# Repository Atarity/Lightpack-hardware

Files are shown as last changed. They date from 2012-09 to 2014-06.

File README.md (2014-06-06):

Lightpack-hardware
==================

Lightpack hardware schematics and layouts in CAD Eagle 6+ . This repo was started privately by reason of R&amp;D.

-------------------------
All updates stores in [CHANGELOG] (/Atarity/Lightpack-hardware/blob/master/CHANGELOG) file
* L &mdash; DIY versions
* T &mdash; mass-production preview versions

No GERBERs, no extension-hashed backups. All research and derivatives in branches.

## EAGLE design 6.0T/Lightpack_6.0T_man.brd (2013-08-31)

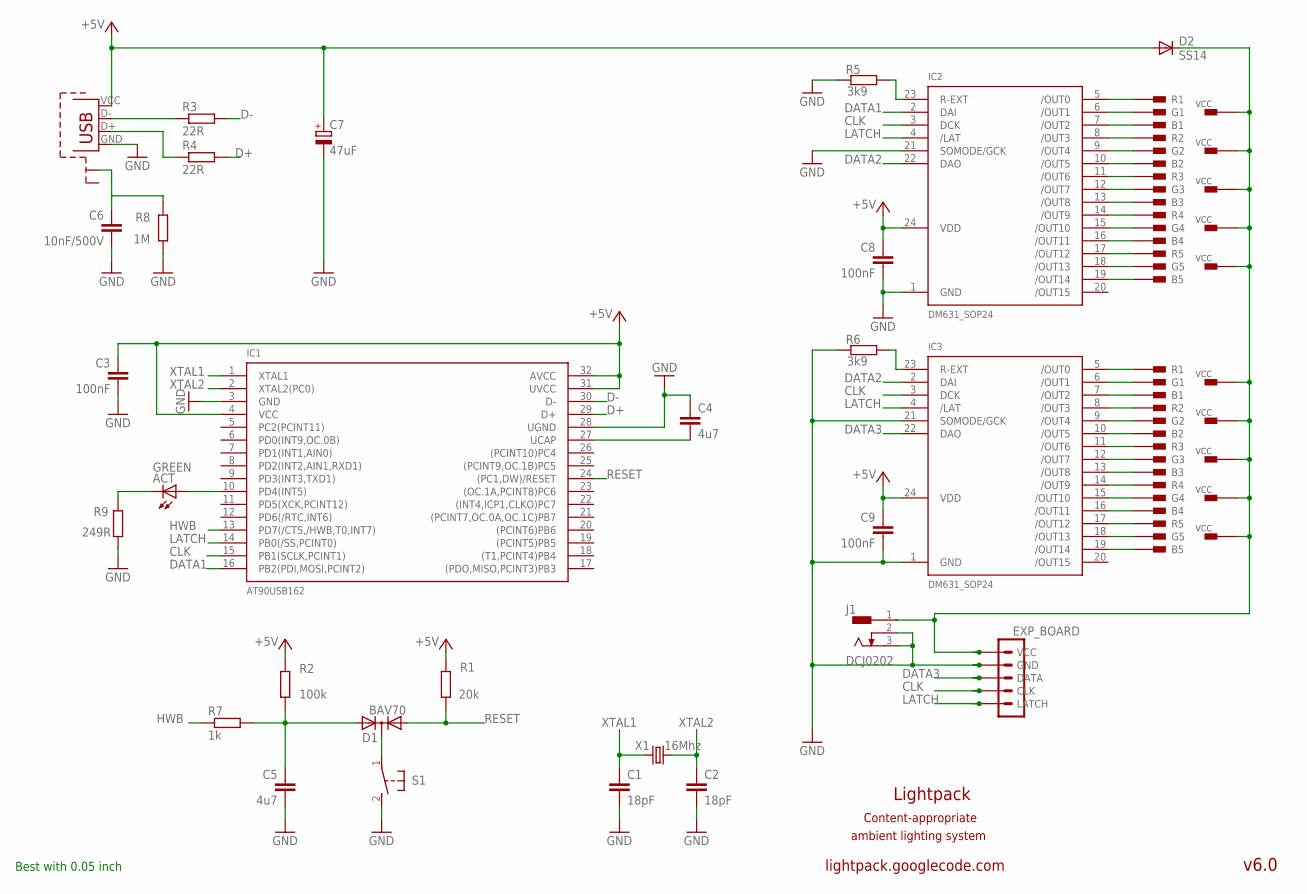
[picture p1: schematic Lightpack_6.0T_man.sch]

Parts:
ACT: GREEN; LED3MM
C1, C2: 18pF; C0805
C3, C8, C9: 100nF; C0805
C4, C5: 4u7; C0805
C6: 10nF/500V; C0805
C7: 47uF; SMC_D
CN1: USB-MICRO-B-EVT; USB-MICRO-B-UNIVERSAL-SOLID-FOOTS
CN2: RJ11-5P-REEL-LIGHTPACK6T2; RJ11-1XN-5P
CN3: RJ11-5P-REEL-MAIN; RJ11-1XN-5P
D1: BAV70; SOT23
D2: SS14; SMB
EXP_BOARD: MA05-1
IC1: AT90USB162; TQFP32
IC2, IC3: DM631_SOP24; SOP24-300-1.27
J1: DCJ0202
R1: 20k; R0805
R2: 100k; R0805
R3, R4: 22R; R0805
R5, R6: 3k9; R0805
R7: 1k; R0805
R8: 1M; R0805
R9: 249R; R0805
S1: 31-XX; B3F-31XX
X1: 16Mhz; HC49UP

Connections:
+5V: C3.1, C7.+, C8.1, C9.1, CN1.VCC (VBUS), D2.A, IC1.4 (VCC), IC1.31 (UVCC), IC1.32 (AVCC), IC2.24 (VDD), IC3.24 (VDD), R1.2, R2.2
CLK: EXP_BOARD.2 (CLK), IC1.15 (PB1(SCLK,PCINT1)), IC2.3 (DCK), IC3.3 (DCK)
D+: IC1.29 (D+), R4.2
D-: IC1.30 (D-), R3.2
DATA1: IC1.16 (PB2(PDI,MOSI,PCINT2)), IC2.2 (DAI)
DATA2: IC2.22 (DAO), IC3.2 (DAI)
DATA3: EXP_BOARD.3 (DATA), IC3.22 (DAO)
GND: C1.2, C2.2, C3.2, C4.1, C5.2, C6.1, C7.-, C8.2, C9.2, CN1.GND, EXP_BOARD.4 (GND), IC1.3 (GND), IC1.28 (UGND), IC2.1 (GND), IC2.21 (SOMODE/GCK), IC3.1 (GND), IC3.21 (SOMODE/GCK), J1.2, J1.3, R5.1, R6.1, R8.1, R9.1, S1.2 (S)
HWB: IC1.13 (PD7(/CTS,/HWB,T0,INT7)), R7.1
LATCH: EXP_BOARD.1 (LATCH), IC1.14 (PB0(/SS,PCINT0)), IC2.4 (/LAT), IC3.4 (/LAT)
unnamed: IC2.23 (R-EXT), R5.2
unnamed: CN3.R2, IC3.8 (/OUT3)
unnamed: ACT.A, IC1.10 (PD4(INT5))
unnamed: CN2.R5 (R1), IC2.5 (/OUT0)
unnamed: CN2.G5 (G1), IC2.6 (/OUT1)
unnamed: CN2.B5 (B1), IC2.7 (/OUT2)
unnamed: CN2.R4 (R2), IC2.8 (/OUT3)
unnamed: CN2.G4 (G2), IC2.9 (/OUT4)
unnamed: CN2.B4 (B2), IC2.10 (/OUT5)
unnamed: CN2.R1 (R3), IC2.11 (/OUT6)
unnamed: CN2.G1 (G3), IC2.12 (/OUT7)
unnamed: CN2.B1 (B3), IC2.13 (/OUT8)
unnamed: CN2.R2 (R4), IC2.14 (/OUT9)
unnamed: D1.3 (C), S1.1
unnamed: C4.2, IC1.27 (UCAP)
unnamed: CN3.R1, IC3.5 (/OUT0)
unnamed: CN3.G1, IC3.6 (/OUT1)
unnamed: CN3.B1, IC3.7 (/OUT2)
unnamed: CN3.G2, IC3.9 (/OUT4)
unnamed: CN3.B2, IC3.10 (/OUT5)
unnamed: CN3.R3, IC3.11 (/OUT6)
unnamed: CN3.G3, IC3.12 (/OUT7)
unnamed: CN3.R4, IC3.14 (/OUT9)
unnamed: CN3.B3, IC3.13 (/OUT8)
unnamed: CN3.G4, IC3.15 (/OUT10)
unnamed: CN3.B4, IC3.16 (/OUT11)
unnamed: CN2.G2 (G4), IC2.15 (/OUT10)
unnamed: CN2.B2 (B4), IC2.16 (/OUT11)
unnamed: IC3.23 (R-EXT), R6.2
unnamed: CN1.D-, R3.1
unnamed: CN1.D+, R4.1
unnamed: ACT.K (C), R9.2
unnamed: CN2.R3 (R5), IC2.17 (/OUT12)
unnamed: CN2.G3 (G5), IC2.18 (/OUT13)
unnamed: CN2.B3 (B5), IC2.19 (/OUT14)
unnamed: CN3.R5, IC3.17 (/OUT12)
unnamed: CN3.G5, IC3.18 (/OUT13)
unnamed: CN3.B5, IC3.19 (/OUT14)
unnamed: C6.2, CN1.P$4 (SHIELD1), R8.2
unnamed: C5.1, D1.2 (A2), R2.1, R7.2
unnamed: CN2.VCC1 (VCC3), CN2.VCC2 (VCC4), CN2.VCC3 (VCC5), CN2.VCC4 (VCC2), CN2.VCC5 (VCC1), CN3.VCC1, CN3.VCC2, CN3.VCC3, CN3.VCC4, CN3.VCC5, D2.C, EXP_BOARD.5 (VCC), J1.1
RESET: D1.1 (A1), IC1.24 ((PC1,DW)/RESET), R1.1
XTAL1: C1.1, IC1.1 (XTAL1), X1.1
XTAL2: C2.1, IC1.2 (XTAL2(PC0)), X1.2

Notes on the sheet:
lightpack.googlecode.com
Lightpack
ambient lighting system
v6.0
Content-appropriate
Best with 0.05 inch

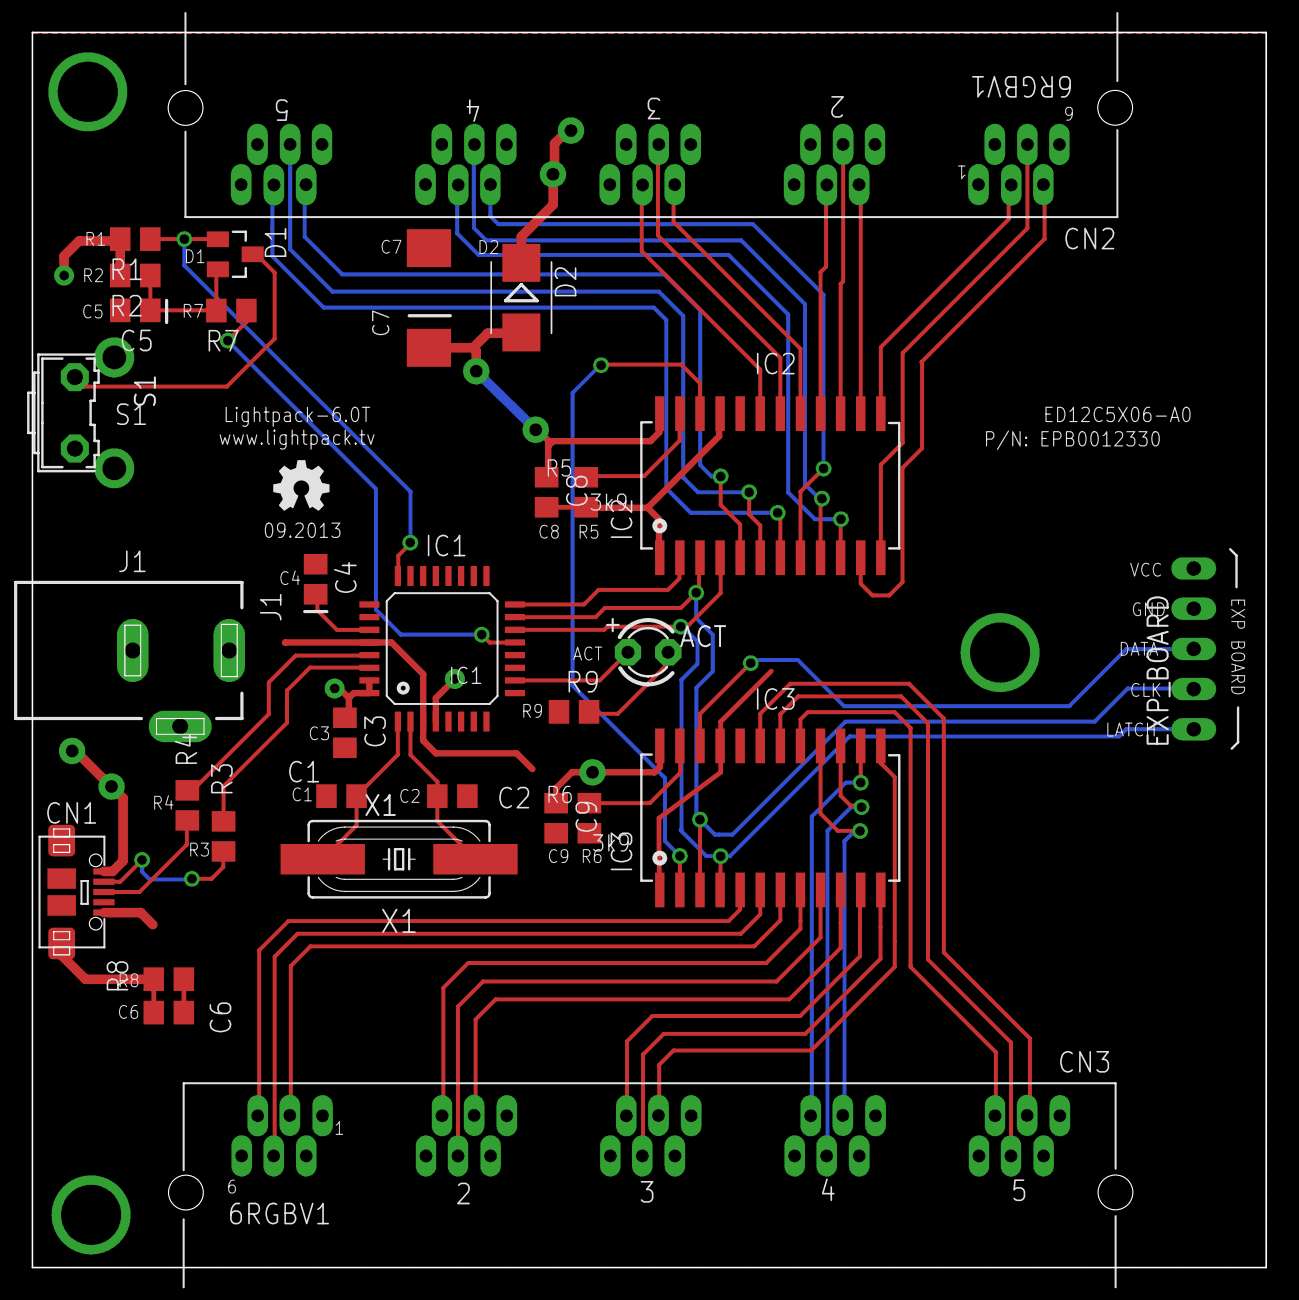
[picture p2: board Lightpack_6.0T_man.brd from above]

Board: 2 copper layers, 78.0 x 78.1 mm, 31 parts (0 on the bottom side), 54 nets.

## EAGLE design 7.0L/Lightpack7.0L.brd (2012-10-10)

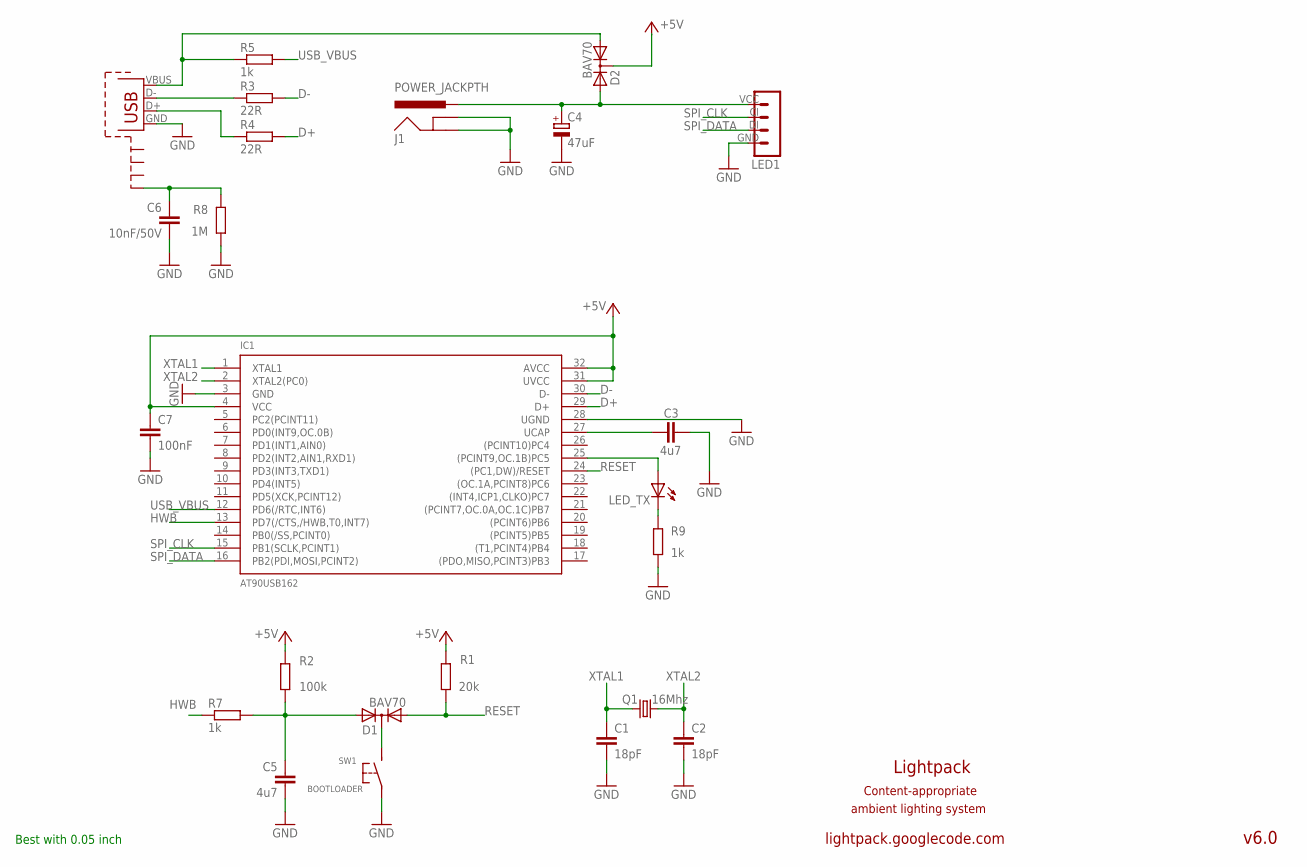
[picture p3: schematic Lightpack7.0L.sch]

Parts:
C1, C2: 18pF; C1206
C3, C5: 4u7; C1206
C4: 47uF; D/7343-31W
C6: 10nF/50V; C1206
C7: 100nF; C1206
D1, D2: BAV70; SOT23
IC1: AT90USB162; TQFP32
J1: POWER_JACKPTH; POWER_JACK_PTH
LED1: RGB_LED_STRIP; MA04-1
LED_TX: GREEN; CHIPLED_0805
Q1: 16Mhz; HC49UP
R1: 20k; R1206
R2: 100k; R1206
R3, R4: 22R; R1206
R5, R7, R9: 1k; R1206
R8: 1M; R1206
SW1: BOOTLOADER; BUTTON-SMD
X1: USB-MB-S

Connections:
+5V: C7.1, IC1.4 (VCC), IC1.31 (UVCC), IC1.32 (AVCC), R1.2, R2.1 (2)
D+: IC1.29 (D+), R4.2
D-: IC1.30 (D-), R3.2
GND: C1.2, C2.2, C3.1, C4.-, C5.2, C6.2, C7.2, IC1.3 (GND), IC1.28 (UGND), J1.GND, J1.GNDBREAK, LED1.GND, R8.1, R9.1, SW1.1, X1.GND
HWB: IC1.13 (PD7(/CTS,/HWB,T0,INT7)), R7.1
unnamed: R4.1, X1.D+
unnamed: D2.1 (A1), R5.1, X1.VBUS
unnamed: R3.1, X1.D-
unnamed: C4.+, D2.2 (A2), J1.PWR, LED1.VCC
unnamed: IC1.25 ((PCINT9,OC.1B)PC5), LED_TX.A
unnamed: C6.1, R8.2, X1.SHIELD4
unnamed: LED_TX.C, R9.2
unnamed: D1.3 (C), SW1.2
unnamed: C5.1, D1.2 (A2), R2.2 (1), R7.2
unnamed: C3.2, IC1.27 (UCAP)
RESET: D1.1 (A1), IC1.24 ((PC1,DW)/RESET), R1.1
SPI_CLK: IC1.15 (PB1(SCLK,PCINT1)), LED1.CI
SPI_DATA: IC1.16 (PB2(PDI,MOSI,PCINT2)), LED1.DI
USB_VBUS: IC1.12 (PD6(/RTC,INT6)), R5.2
XTAL1: C1.1, IC1.1 (XTAL1), Q1.1
XTAL2: C2.1, IC1.2 (XTAL2(PC0)), Q1.2

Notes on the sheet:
lightpack.googlecode.com
Lightpack
ambient lighting system
v6.0
Content-appropriate
Best with 0.05 inch

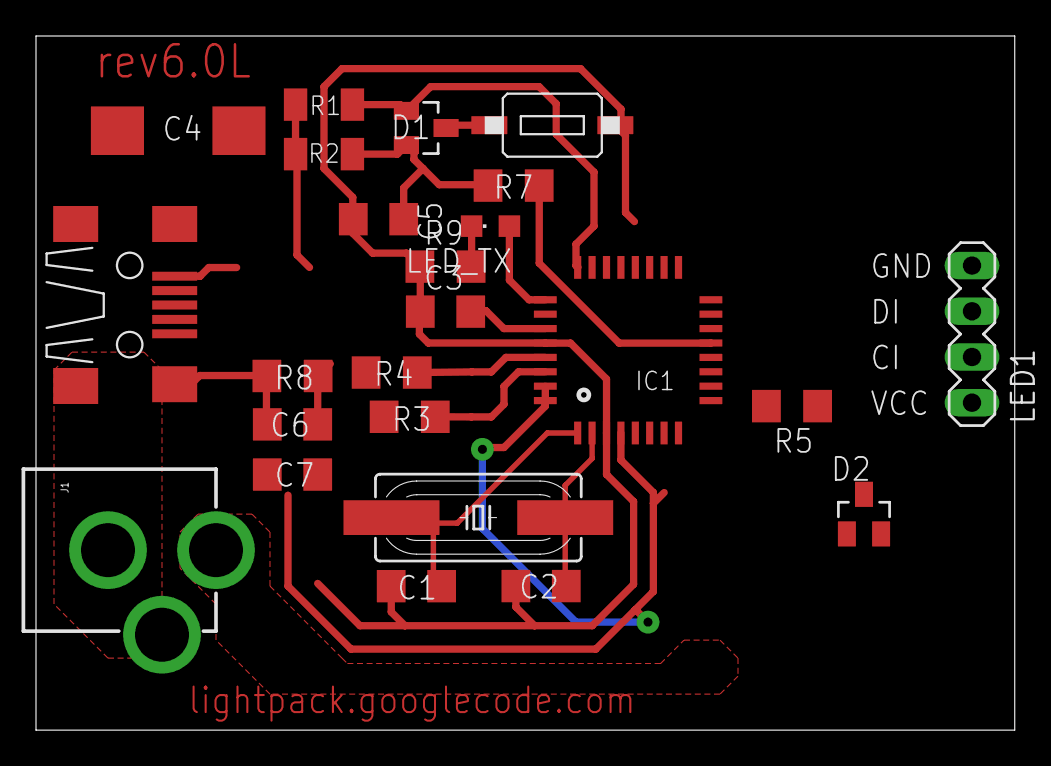
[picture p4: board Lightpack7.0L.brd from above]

Board: 2 copper layers, 54.4 x 38.6 mm, 24 parts (0 on the bottom side), 21 nets.

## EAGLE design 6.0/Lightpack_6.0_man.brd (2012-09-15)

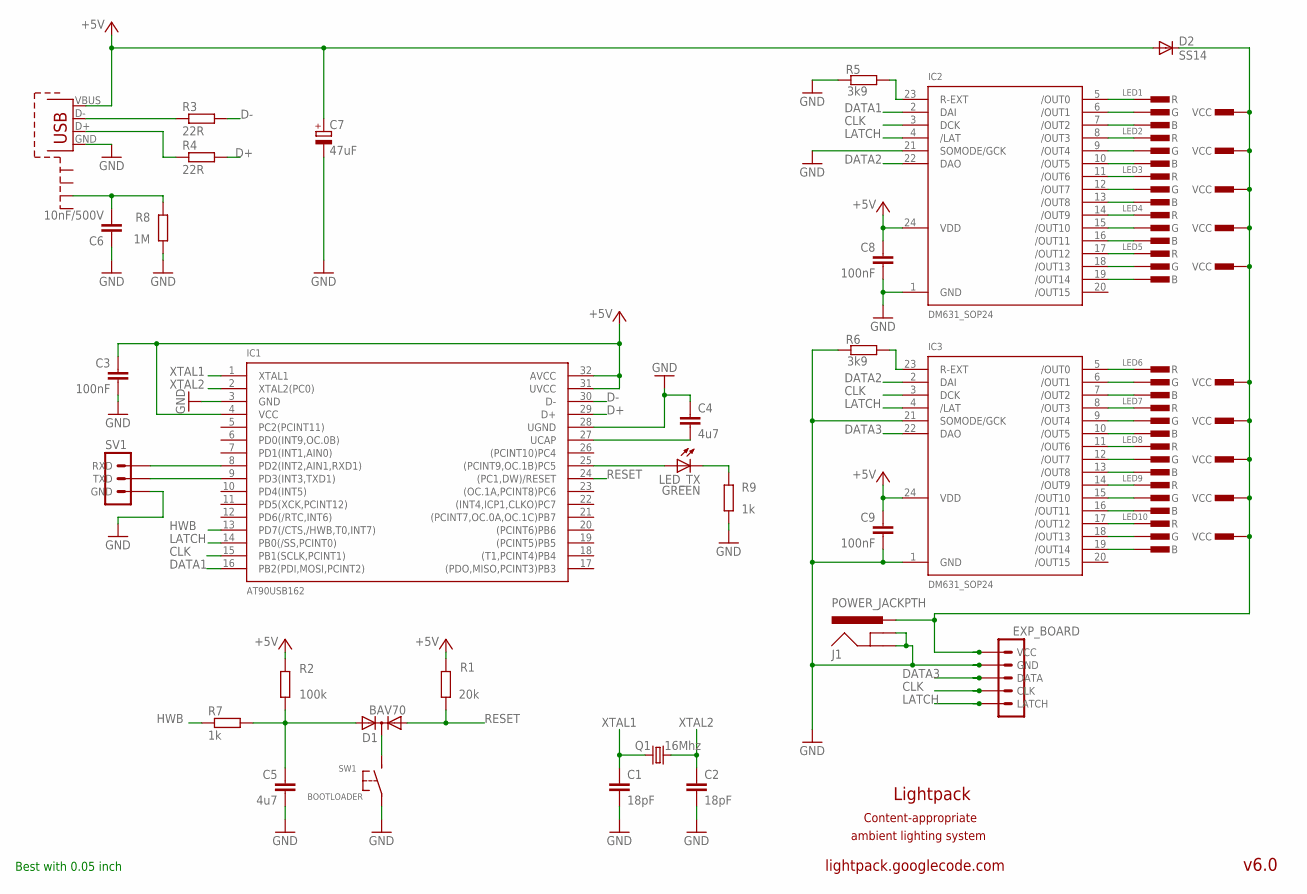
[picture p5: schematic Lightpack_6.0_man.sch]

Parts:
C1, C2: 18pF; C0805
C3, C8, C9: 100nF; C0805
C4, C5: 4u7; C0805
C6: 10nF/500V; C0805
C7: 47uF; SMC_D
D1: BAV70; SOT23
D2: SS14; SMB
EXP_BOARD: MA05-1
IC1: AT90USB162; TQFP32
IC2, IC3: DM631_SOP24; SOP24-300-1.27
J1: POWER_JACKPTH; POWER_JACK_PTH
LED1, LED2, LED3, LED4, LED5, LED6, LED7, LED8, LED9, LED10: CON-RGB-LED; CON-RGB-LED-TH
LED_TX: GREEN; CHIPLED_0805
Q1: 16Mhz; HC49UP
R1: 20k; R0805
R2: 100k; R0805
R3, R4: 22R; R0805
R5, R6: 3k9; R0805
R7, R9: 1k; R0805
R8: 1M; R0805
SV1: UART3
SW1: BOOTLOADER; BUTTON-SMD
X1: USB-MB-S

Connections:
+5V: C3.1, C7.+, C8.1, C9.1, D2.A, IC1.4 (VCC), IC1.31 (UVCC), IC1.32 (AVCC), IC2.24 (VDD), IC3.24 (VDD), R1.2, R2.2, X1.VBUS
CLK: EXP_BOARD.2 (CLK), IC1.15 (PB1(SCLK,PCINT1)), IC2.3 (DCK), IC3.3 (DCK)
D+: IC1.29 (D+), R4.2
D-: IC1.30 (D-), R3.2
DATA1: IC1.16 (PB2(PDI,MOSI,PCINT2)), IC2.2 (DAI)
DATA2: IC2.22 (DAO), IC3.2 (DAI)
DATA3: EXP_BOARD.3 (DATA), IC3.22 (DAO)
GND: C1.2, C2.2, C3.2, C4.1, C5.2, C6.1, C7.-, C8.2, C9.2, EXP_BOARD.4 (GND), IC1.3 (GND), IC1.28 (UGND), IC2.1 (GND), IC2.21 (SOMODE/GCK), IC3.1 (GND), IC3.21 (SOMODE/GCK), J1.GND, J1.GNDBREAK, R5.1, R6.1, R8.1, R9.1, SV1.1-L (GND), SW1.1, X1.GND
HWB: IC1.13 (PD7(/CTS,/HWB,T0,INT7)), R7.1
LATCH: EXP_BOARD.1 (LATCH), IC1.14 (PB0(/SS,PCINT0)), IC2.4 (/LAT), IC3.4 (/LAT)
unnamed: IC2.23 (R-EXT), R5.2
unnamed: IC3.8 (/OUT3), LED7.3.R (R)
unnamed: IC1.8 (PD2(INT2,AIN1,RXD1)), SV1.2 (RXD)
unnamed: IC1.9 (PD3(INT3,TXD1)), SV1.3-R (TXD)
unnamed: IC2.5 (/OUT0), LED1.3.R (R)
unnamed: IC2.6 (/OUT1), LED1.2.G (G)
unnamed: IC2.7 (/OUT2), LED1.1.B (B)
unnamed: IC1.25 ((PCINT9,OC.1B)PC5), LED_TX.A
unnamed: IC2.8 (/OUT3), LED2.3.R (R)
unnamed: IC2.9 (/OUT4), LED2.2.G (G)
unnamed: IC2.10 (/OUT5), LED2.1.B (B)
unnamed: IC2.11 (/OUT6), LED3.3.R (R)
unnamed: IC2.12 (/OUT7), LED3.2.G (G)
unnamed: IC2.13 (/OUT8), LED3.1.B (B)
unnamed: IC2.14 (/OUT9), LED4.3.R (R)
unnamed: C4.2, IC1.27 (UCAP)
unnamed: IC3.5 (/OUT0), LED6.3.R (R)
unnamed: IC3.6 (/OUT1), LED6.2.G (G)
unnamed: IC3.7 (/OUT2), LED6.1.B (B)
unnamed: IC3.9 (/OUT4), LED7.2.G (G)
unnamed: IC3.10 (/OUT5), LED7.1.B (B)
unnamed: IC3.11 (/OUT6), LED8.3.R (R)
unnamed: IC3.12 (/OUT7), LED8.2.G (G)
unnamed: IC3.14 (/OUT9), LED9.3.R (R)
unnamed: IC3.13 (/OUT8), LED8.1.B (B)
unnamed: IC3.15 (/OUT10), LED9.2.G (G)
unnamed: IC3.16 (/OUT11), LED9.1.B (B)
unnamed: IC2.15 (/OUT10), LED4.2.G (G)
unnamed: IC2.16 (/OUT11), LED4.1.B (B)
unnamed: IC3.23 (R-EXT), R6.2
unnamed: R3.1, X1.D-
unnamed: R4.1, X1.D+
unnamed: LED_TX.C, R9.2
unnamed: IC2.17 (/OUT12), LED5.3.R (R)
unnamed: IC2.18 (/OUT13), LED5.2.G (G)
unnamed: IC2.19 (/OUT14), LED5.1.B (B)
unnamed: IC3.17 (/OUT12), LED10.3.R (R)
unnamed: IC3.18 (/OUT13), LED10.2.G (G)
unnamed: IC3.19 (/OUT14), LED10.1.B (B)
unnamed: C6.2, R8.2, X1.SHIELD3
unnamed: D1.3 (C), SW1.2
unnamed: C5.1, D1.2 (A2), R2.1, R7.2
unnamed: D2.C, EXP_BOARD.5 (VCC), J1.PWR, LED1.4.VCC (VCC), LED2.4.VCC (VCC), LED3.4.VCC (VCC), LED4.4.VCC (VCC), LED5.4.VCC (VCC), LED6.4.VCC (VCC), LED7.4.VCC (VCC), LED8.4.VCC (VCC), LED9.4.VCC (VCC), LED10.4.VCC (VCC)
RESET: D1.1 (A1), IC1.24 ((PC1,DW)/RESET), R1.1
XTAL1: C1.1, IC1.1 (XTAL1), Q1.1
XTAL2: C2.1, IC1.2 (XTAL2(PC0)), Q1.2

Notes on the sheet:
lightpack.googlecode.com
Lightpack
ambient lighting system
v6.0
Content-appropriate
Best with 0.05 inch

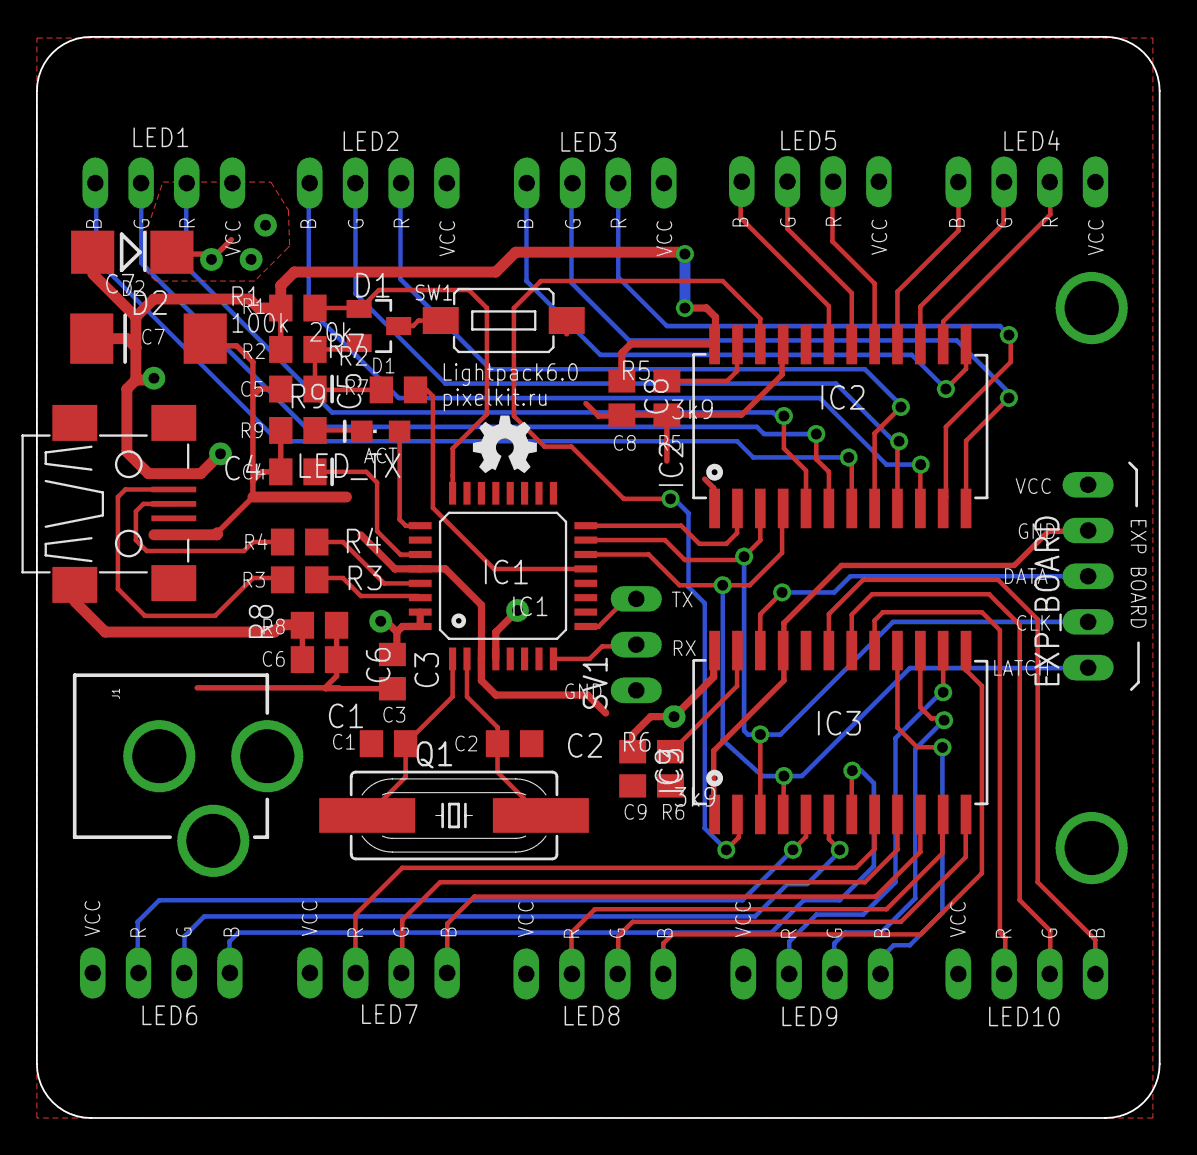
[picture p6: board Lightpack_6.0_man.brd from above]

Board: 2 copper layers, 62.4 x 60.1 mm, 40 parts (0 on the bottom side), 56 nets.

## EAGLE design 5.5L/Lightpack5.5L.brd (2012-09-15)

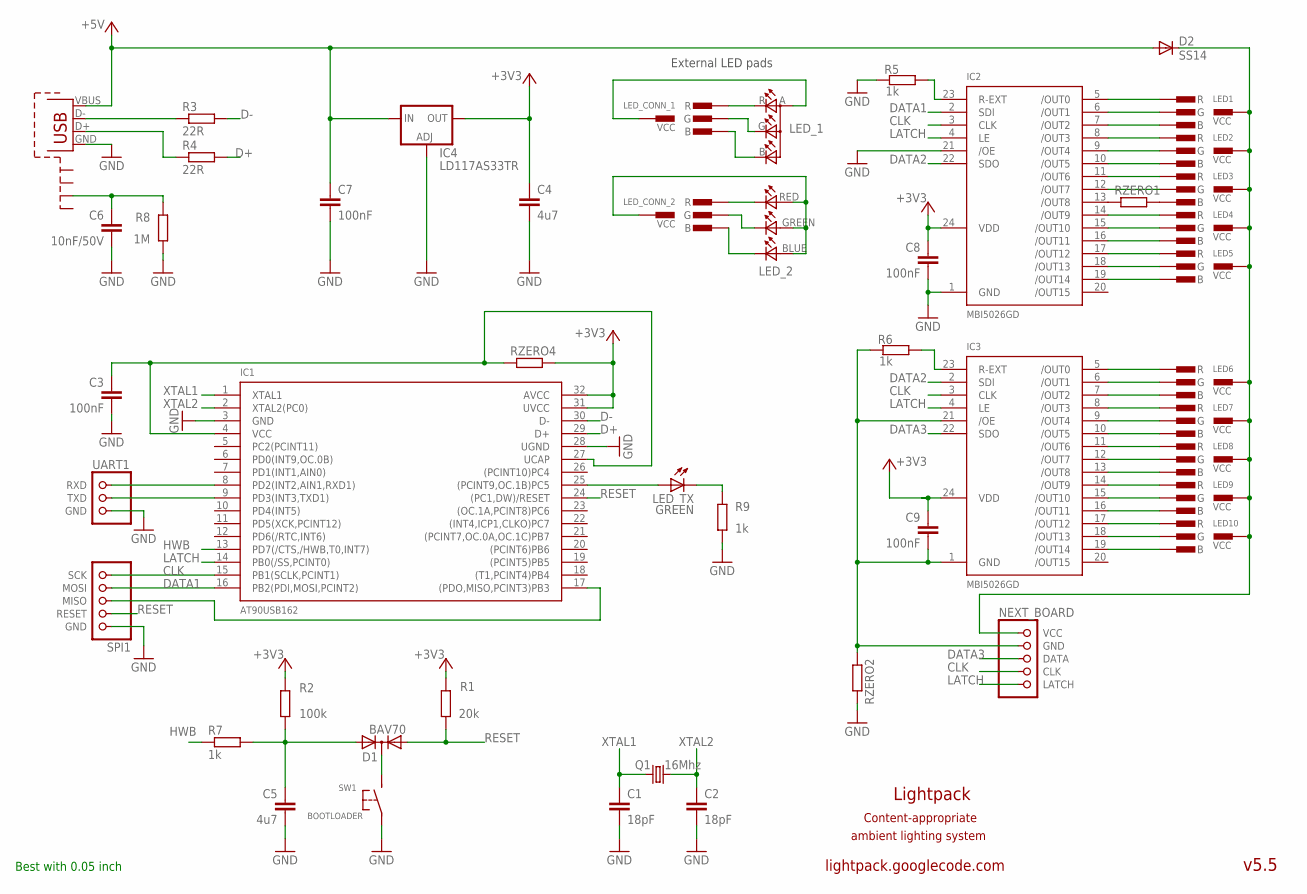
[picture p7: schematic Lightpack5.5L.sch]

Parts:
C1, C2: 18pF; C1206
C3, C7, C8, C9: 100nF; C1206
C4, C5: 4u7; C1206
C6: 10nF/50V; C1206
D1: BAV70; SOT23
D2: SS14; SMB
IC1: AT90USB162; TQFP32
IC2, IC3: MBI5026GD; SOP24-300-1.27
IC4: LD117AS33TR; SOT223
LED1, LED2, LED3, LED6, LED7, LED8, LED9, LED10: CON-RGB-LED
LED4, LED5: CON-RGB-LEDVCC-INDENT; CON-RGB-LED-WITH-VCC-INDENT
LED_1: CLV1A-FKB
LED_2: TOPLED-3SMD5X5; SMD-RGB-5X5
LED_CONN_1, LED_CONN_2: CON-RGB-LED
LED_TX: GREEN; CHIPLED_0805
NEXT_BOARD: LED_DRIVER_BOARD; DATA-CLK-LATCH
Q1: 16Mhz; HC49UP
R1: 20k; R1206
R2: 100k; R1206
R3, R4: 22R; R1206
R5, R6, R7, R9: 1k; R1206
R8: 1M; R1206
RZERO1, RZERO4: R-EU_R1206_2; R1206
RZERO2: 0; R1206
SPI1: SPI_RST_GND_CONN; SPI_5
SW1: BOOTLOADER; BUTTON-SMD
UART1: UART
X1: USB-MB-S

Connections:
+3V3: C4.1, C8.1, C9.1, IC1.31 (UVCC), IC1.32 (AVCC), IC2.24 (VDD), IC3.24 (VDD), IC4.4 (OUT), R1.2, R2.1 (2), RZERO4.1 (2)
+5V: C7.1, D2.A, IC4.3 (IN), X1.VBUS
CLK: IC1.15 (PB1(SCLK,PCINT1)), IC2.3 (CLK), IC3.3 (CLK), NEXT_BOARD.CLK, SPI1.SCK
D+: IC1.29 (D+), R4.2
D-: IC1.30 (D-), R3.2
DATA1: IC1.16 (PB2(PDI,MOSI,PCINT2)), IC2.2 (SDI), SPI1.MOSI
DATA2: IC2.22 (SDO), IC3.2 (SDI)
DATA3: IC3.22 (SDO), NEXT_BOARD.DATA
GND: C1.2, C2.2, C3.2, C4.2, C5.2, C6.2, C7.2, C8.2, IC1.3 (GND), IC1.28 (UGND), IC2.1 (GND), IC2.21 (/OE), IC4.1 (ADJ), R5.1, R8.1, R9.1, RZERO2.1 (2), SPI1.GND, SW1.1, UART1.GND, X1.GND
HWB: IC1.13 (PD7(/CTS,/HWB,T0,INT7)), R7.1
LATCH: IC1.14 (PB0(/SS,PCINT0)), IC2.4 (LE), IC3.4 (LE), NEXT_BOARD.LATCH
unnamed: IC2.23 (R-EXT), R5.2
unnamed: IC3.8 (/OUT3), LED7.R
unnamed: IC1.17 ((PDO,MISO,PCINT3)PB3), SPI1.MISO
unnamed: IC1.8 (PD2(INT2,AIN1,RXD1)), UART1.RXD
unnamed: IC2.5 (/OUT0), LED1.R
unnamed: IC2.6 (/OUT1), LED1.G
unnamed: IC2.7 (/OUT2), LED1.B
unnamed: IC1.25 ((PCINT9,OC.1B)PC5), LED_TX.A
unnamed: IC2.8 (/OUT3), LED2.R
unnamed: IC2.9 (/OUT4), LED2.G
unnamed: IC2.10 (/OUT5), LED2.B
unnamed: IC2.11 (/OUT6), LED3.R
unnamed: IC2.12 (/OUT7), LED3.G
unnamed: IC2.13 (/OUT8), RZERO1.2 (1)
unnamed: IC2.14 (/OUT9), LED4.R
unnamed: IC1.9 (PD3(INT3,TXD1)), UART1.TXD
unnamed: LED_1.R (CRED), LED_CONN_1.R
unnamed: IC3.5 (/OUT0), LED6.R
unnamed: IC3.6 (/OUT1), LED6.G
unnamed: IC3.7 (/OUT2), LED6.B
unnamed: IC3.9 (/OUT4), LED7.G
unnamed: IC3.10 (/OUT5), LED7.B
unnamed: IC3.11 (/OUT6), LED8.R
unnamed: IC3.12 (/OUT7), LED8.G
unnamed: IC3.14 (/OUT9), LED9.R
unnamed: IC3.13 (/OUT8), LED8.B
unnamed: IC3.15 (/OUT10), LED9.G
unnamed: IC3.16 (/OUT11), LED9.B
unnamed: IC2.15 (/OUT10), LED4.G
unnamed: IC2.16 (/OUT11), LED4.B
unnamed: IC3.23 (R-EXT), R6.2
unnamed: R3.1, X1.D-
unnamed: R4.1, X1.D+
unnamed: LED_1.G (CGREEN), LED_CONN_1.G
unnamed: LED_1.B (CBLUE), LED_CONN_1.B
unnamed: LED_1.A (ANODE), LED_CONN_1.VCC
unnamed: LED_TX.C, R9.2
unnamed: IC2.17 (/OUT12), LED5.R
unnamed: IC2.18 (/OUT13), LED5.G
unnamed: IC2.19 (/OUT14), LED5.B
unnamed: IC3.17 (/OUT12), LED10.R
unnamed: IC3.18 (/OUT13), LED10.G
unnamed: IC3.19 (/OUT14), LED10.B
unnamed: C6.1, R8.2, X1.SHIELD3
unnamed: D1.3 (C), SW1.2
unnamed: C5.1, D1.2 (A2), R2.2 (1), R7.2
unnamed: C9.2, IC3.1 (GND), IC3.21 (/OE), NEXT_BOARD.GND, R6.1, RZERO2.2 (1)
unnamed: LED3.B, RZERO1.1 (2)
unnamed: LED_2.CRED, LED_CONN_2.R
unnamed: LED_2.CGREEN, LED_CONN_2.G
unnamed: LED_2.CBLUE, LED_CONN_2.B
unnamed: C3.1, IC1.4 (VCC), IC1.27 (UCAP), RZERO4.2 (1)
unnamed: LED_2.BLUE, LED_2.GREEN, LED_2.RED, LED_CONN_2.VCC
unnamed: D2.C, LED1.VCC, LED2.VCC, LED3.VCC, LED4.VCC, LED5.VCC, LED6.VCC, LED7.VCC, LED8.VCC, LED9.VCC, LED10.VCC, NEXT_BOARD.VCC
RESET: D1.1 (A1), IC1.24 ((PC1,DW)/RESET), R1.1, SPI1.RESET
XTAL1: C1.1, IC1.1 (XTAL1), Q1.1
XTAL2: C2.1, IC1.2 (XTAL2(PC0)), Q1.2

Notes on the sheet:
lightpack.googlecode.com
Lightpack
ambient lighting system
v5.5
Content-appropriate
External LED pads
Best with 0.05 inch

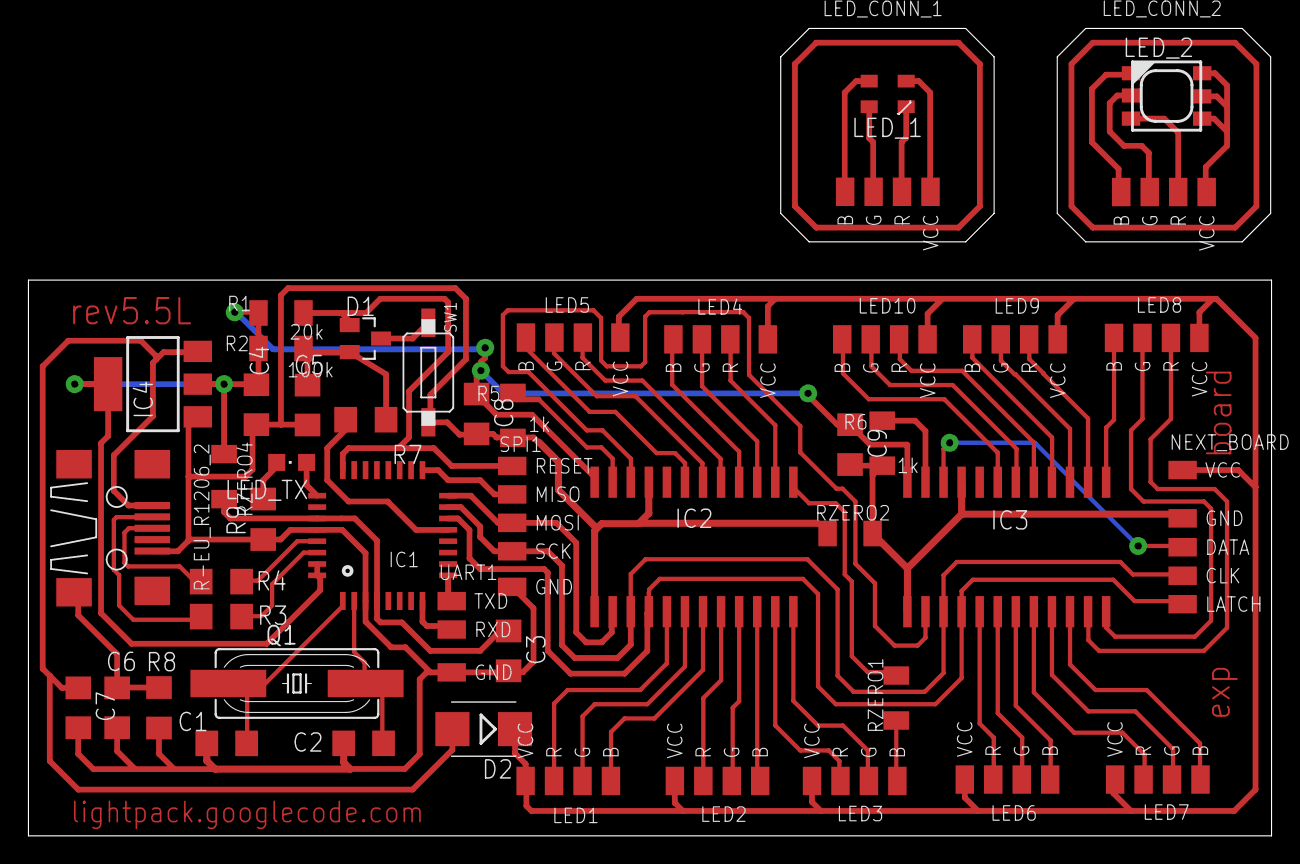
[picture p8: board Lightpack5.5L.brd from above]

Board: 2 copper layers, 87.4 x 39.1 mm, 48 parts (0 on the bottom side), 68 nets.

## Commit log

2012-09-15 Initial tree commit, all in Eagle 6+
    * 5.5, 5.5L, 5.6, 6.0, 6.0L, 6.0T schematic and layouts
    * gitignor
    * CHANGELOG actualized
    [Lightpack5.5.brd, Lightpack5.5.sch, Lightpack5.5L.brd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]
2012-09-16 Front-line I/O rearranged
    * Button --> DJK02A --> microUSB
    * Expand PCB size for Alex case
    * Bottom polygons shape changes
    [Lightpack_6.0T_man.brd, Lightpack_6.0T_man.sch]
2012-09-17 60T improved for casing
    * PCB size 76x71mm now
    * UART deletted
    * ACT LED now on pin 10 instead 25 (need to modify firmware)
    * ACT LED thru-hole d3 now (need to test R9)
    * 3 mount holes d3 od5
    * Significanty alot of space between components
    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
    [Lightpack_6.0T_man.brd, Lightpack_6.0T_man.sch]
2012-09-28 Top restriction added, minor changes on bottom.
    *GERBERS ignored in .gitignore
    [Lightpack_6.0T_man.brd]
2012-10-02 I/O names for tPlace added and rearranged.
    [Lightpack_6.0T_man.brd, Lightpack_6.0T_man.sch]
2012-10-04 Extended 78x78 version
    *Mount holes fixed
    *Dimensions fixed
    *Polylines fixed
    [Lightpack_6.0T_man.brd]
2012-10-08 microUSB footprint adjust for pointer welding
    [Lightpack_6.0T_man.brd, Lightpack_6.0T_man.sch]
2012-10-09 New universal microUSB footprint
    *Some restriction added
    *7 holes on milling (46) layer
    [Lightpack_6.0T_man.brd, Lightpack_6.0T_man.sch]
2012-10-10 Basic Lightpack 7 schematics
    Support power from PSU and USB (split by diode BAV70).
    Added resistor (1k) for determine USB-power status.
    [Lightpack7.0L.brd, Lightpack7.0L.sch]
2012-10-18 Fix names and R9 value
    [Lightpack_6.0T_man.brd, Lightpack_6.0T_man.sch]
2013-07-22 Draft-angle enclosure type optimization
    * tPlace silk updated (url, year)
    * CN2, CN3 moved toward PCB center for 1mm
    [Lightpack_6.0T_man.brd]
2013-08-02 tSilk + new microUSB socket + CN2,CN3 moving (see details)
    -- P/N + ID on tSilk
    -- Slots of mUSB increased to 1.0x0.5mm
    -- New solid rect in mUSB component (commited in Pixelkit lib) named EVT
    -- CN2,3 moved on 0.1mm out of center
    [Lightpack_6.0T_man.brd, Lightpack_6.0T_man.sch]
2013-08-06 update microUSB foots for EVT (see EAGLE-libs commit)
    [Lightpack_6.0T_man.brd, Lightpack_6.0T_man.sch]
2013-08-31 LED, RJ11 reel, Soldermask
    — Indicator LED shifted to the exp board on 1.3 mm
    — RJ11 reel pads with increased drill diameter
    — All vias up to 0.6 diameters now covers with soldermask
    [Lightpack_6.0T_man.brd, Lightpack_6.0T_man.sch]
